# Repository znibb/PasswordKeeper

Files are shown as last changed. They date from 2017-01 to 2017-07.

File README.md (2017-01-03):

# PasswordKeeper
Ever gotten tired manually inputing your password everytime you unlock your desktop? PasswordKeeper let's you use a RFID/NFC tag to input a password into your computer!
## About

The device consists of a custom designed circuit that uses an Atmega32u4 MCU to interface a MFRC522 contactless reader to any computer by emulating a keyboard over a USB connection, no driver or external software required!

The device stores a list of tags with an assoiciated password in the EEPROM of the MCU. When a user scans a tag the program returns the corresponding password as emulated keyboard presses. The sketch used to store user credentials in EEPROM can be found here: https://github.com/znibb/PasswordKeeper_loadData/.

## Usage
### Store user credentials
1. Download the loadData sketch from: https://github.com/znibb/PasswordKeeper_loadData/.
2. Copy `src/PasswordKeeper_loadData.ino.template` to `src/PasswordKeeper_loadData.ino`.
3. Edit loadData sketch with appropriate user credentials.
4. Upload loadData sketch.
5. Open a serial connection to the device to initialize the writing to EEPROM and to get feedback on the results.
6. Done.

### Prepare for operation
1. Clone/download the sketch from this repository.
2. Upload sketch.
3. Ready for use!

## Tips & tricks
- Don't know the UID of your tag? 
  - Upload the sketch and start a serial monitor. The sketch will output the UID of any scanned tag on the serial bus.

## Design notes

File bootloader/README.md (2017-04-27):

# Bootloader tools
* Software
  - Blink.hex
    - Compiled standard Blink sketch.
  - Blink_with_bl.hex
    - Same as above but also contains the bootloader section.
  - Caterina-Leonardo.hex
    - Standard Arduino Leonardo bootloader.
* Scripts
  - dfuUpload.sh
    - Flash software over USB to a MCU in DFU mode.
  - load_bootloader.sh
    - Burn bootloader using avrdude and a AVRISP2 programmer.
  - read_fuses.sh
    - Read out fuse values using avrdude and a AVRISP2 programmer. Stores the values in separate txt files.
  - write_fuses.sh
    - Set fuse values to suitable values, described in 'fuses.txt'
* Information
  - fuses.txt
    - Explains the used fuse values

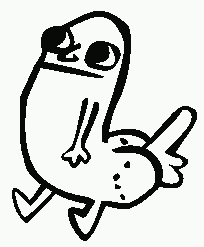
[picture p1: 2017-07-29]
hardware/db_204x247.bmp

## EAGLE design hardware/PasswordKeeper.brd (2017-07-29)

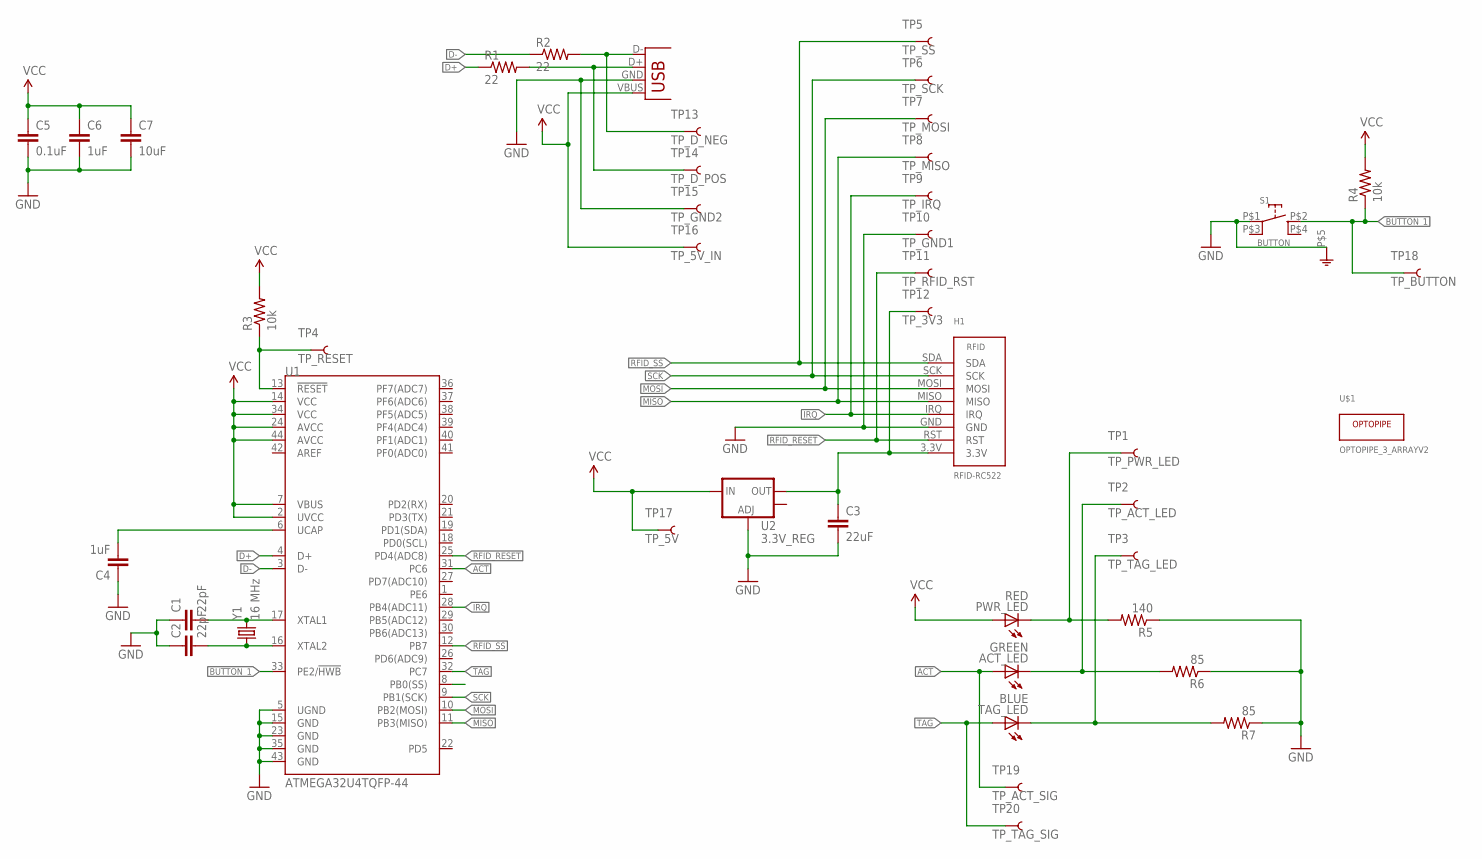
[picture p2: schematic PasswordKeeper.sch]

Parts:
ACT_LED: GREEN; LED-1206
C1, C2: 22pF; 1206
C3: 22uF; 0805
C4, C6: 1uF; 1206
C5: 0.1uF; 1206
C7: 10uF; 1206
H1: RFID-RC522; EXT_RFID_READER
JP1: USB-A-H
PWR_LED: RED; LED-1206
R1, R2: 22; 1206
R3, R4: 10k; 1206
R5: 140; 1206
R6, R7: 85; 1206
S1: BUTTON; TACTILE_SWITCH_SMD_RIGHT_ANGLE
TAG_LED: BLUE; LED-1206
TP1: TP_PWR_LED; TP_15TH
TP2: TP_ACT_LED; TP_15TH
TP3: TP_TAG_LED; TP_15TH
TP4: TP_RESET; TP_15TH
TP5: TP_SS; TP_15TH
TP6: TP_SCK; TP_15TH
TP7: TP_MOSI; TP_15TH
TP8: TP_MISO; TP_15TH
TP9: TP_IRQ; TP_15TH
TP10: TP_GND1; TP_15TH
TP11: TP_RFID_RST; TP_15TH
TP12: TP_3V3; TP_15TH
TP13: TP_D_NEG; TP_15TH
TP14: TP_D_POS; TP_15TH
TP15: TP_GND2; TP_15TH
TP16: TP_5V_IN; TP_15TH
TP17: TP_5V; TP_15TH
TP18: TP_BUTTON; TP_15TH
TP19: TP_ACT_SIG; TP_15TH
TP20: TP_TAG_SIG; TP_15TH
U1: ATMEGA32U4TQFP-44; TQFP44
U2: 3.3V_REG; SOT223
U$1: OPTOPIPE_3_ARRAYV2; 515-1000_V2
Y1: 16 MHz; HC49UP

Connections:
3.3V: C3.1, H1.3.3V, TP12.P$1, U2.2 (OUT)
ACT: ACT_LED.A, TP19.P$1, U1.31 (PC6)
BUTTON_1: R4.1, S1.P$2, TP18.P$1, U1.33 (PE2/!HWB)
D+: R1.1, U1.4 (D+)
D-: R2.1, U1.3 (D-)
GND: C1.1, C2.1, C3.2, C4.1, C5.2, C6.2, C7.2, H1.GND, JP1.GND (VBUS), R5.1, R6.1, R7.1, S1.P$1, S1.P$5, TP10.P$1, TP15.P$1, U1.5 (UGND), U1.15 (GND), U1.23 (GND), U1.35 (GND), U1.43 (GND), U2.1 (ADJ)
IRQ: H1.IRQ, TP9.P$1, U1.28 (PB4(ADC11))
MISO: H1.MISO, TP8.P$1, U1.11 (PB3(MISO))
MOSI: H1.MOSI, TP7.P$1, U1.10 (PB2(MOSI))
unnamed: JP1.D- (D+), R2.2, TP13.P$1
unnamed: JP1.D+ (D-), R1.2, TP14.P$1
unnamed: C1.2, U1.17 (XTAL1), Y1.2
unnamed: C2.2, U1.16 (XTAL2), Y1.1
unnamed: C4.2, U1.6 (UCAP)
unnamed: PWR_LED.C, R5.2, TP1.P$1
unnamed: ACT_LED.C, R6.2, TP2.P$1
unnamed: R7.2, TAG_LED.C, TP3.P$1
PROG_SS: U1.8 (PB0(SS))
RESET: R3.1, TP4.P$1, U1.13 (!RESET)
RFID_RESET: H1.RST, TP11.P$1, U1.25 (PD4(ADC8))
RFID_SS: H1.SDA, TP5.P$1, U1.12 (PB7)
SCK: H1.SCK, TP6.P$1, U1.9 (PB1(SCK))
TAG: TAG_LED.A, TP20.P$1, U1.32 (PC7)
VCC: C5.1, C6.1, C7.1, JP1.VBUS (GND), PWR_LED.A, R3.2, R4.2, TP16.P$1, TP17.P$1, U1.2 (UVCC), U1.7 (VBUS), U1.14 (VCC), U1.24 (AVCC), U1.34 (VCC), U1.44 (AVCC), U2.3 (IN)

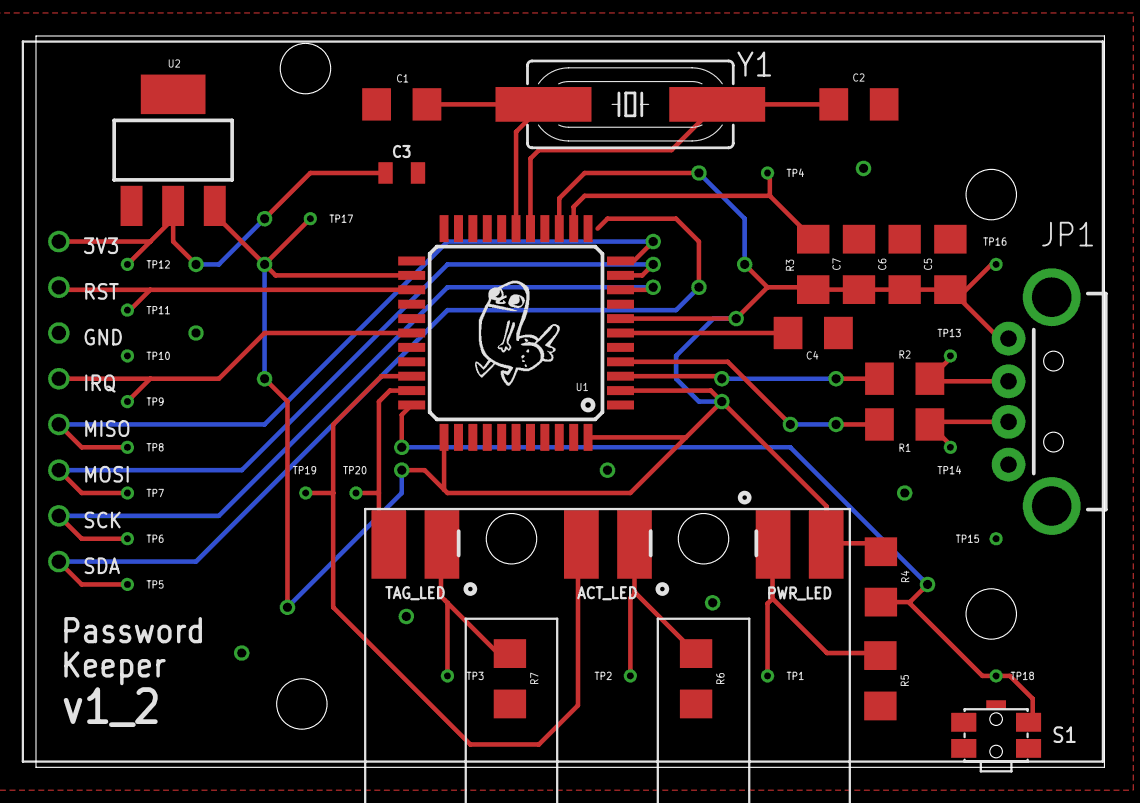
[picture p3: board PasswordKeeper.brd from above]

Board: 2 copper layers, 59.4 x 40.6 mm, 44 parts (0 on the bottom side), 23 nets.

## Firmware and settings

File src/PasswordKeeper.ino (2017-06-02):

#include <Arduino.h>
#include <EEPROM.h>
#include <Keyboard.h>
#include <MFRC522.h>
#include <TagData.h>

//#define DEBUG

// Pin definitions
#define RST_PIN 4
#define SS_PIN 11
#define ACT_LED_PIN 5
#define TAG_LED_PIN 13
#define BUTTON_PIN "PE2"

// Parameters
const int blinkDelay = 500;
const int authDelay = 2000;
const int tagDelay = 1000;
const int loopDelay = 1000;

// Variables
unsigned long actExpirationTime;
unsigned long tagExpirationTime;
byte nbr_of_tags;
byte uid_size;
byte pwd_size;

// Object for containing user data
TagData userData;

// Initialize RFID reader object
MFRC522 rfid(SS_PIN, RST_PIN);

// Function prototypes
boolean buttonState(String);
boolean checkPair(byte[], byte[]);
void enableLed(byte, const int);
void flashLeds(byte);
void ledHandler(void);

void setup(){
  // Init serial port
  Serial.begin(115200);

  #ifdef DEBUG
  // Wait for  serial port to start so no printouts are missed
  while(!Serial);
  #endif

  // Init RFID reader
  SPI.begin();
  rfid.PCD_Init();

  // Adjust RFID reader antenna gain
  rfid.PCD_SetAntennaGain(rfid.RxGain_max);

  // Set pin modes
  pinMode(ACT_LED_PIN, OUTPUT);
  pinMode(TAG_LED_PIN, OUTPUT);
  DDRE &= B11111011;  // Set PE2 as input

  // Load user meta data from EEPROM
  nbr_of_tags = EEPROM.read(0);
  uid_size    = EEPROM.read(1);
  pwd_size    = EEPROM.read(2);

  // Initialize data storage object
  userData = TagData(nbr_of_tags, uid_size, pwd_size);

  // Load user data from EEPROM
  int memAddr = 3;  // User data starts at the 4th byte (index 3)
  // Parse one uid/pwd pair at a time
  for(int i = 0; i < nbr_of_tags; i++){
    // Parse uid
    byte uid[uid_size];
    for(int j = 0; j < uid_size; j++){
      uid[j] = EEPROM.read(memAddr);
      memAddr++;
    }
    userData.tags[i].setUid(uid);

    // Parse password
    char pwd[pwd_size];
    for(int j = 0; j < pwd_size; j++){
      pwd[j] = EEPROM.read(memAddr);
      memAddr++;
    }
    userData.tags[i].setPwd(pwd);
  }
  Serial.print("Loaded ");
  Serial.print(nbr_of_tags);
  Serial.println(" tags.");

//=============================================
  #ifdef DEBUG
  // Dump all retrieved data to Serial
  byte uid[uid_size];
  char pwd[pwd_size];

  for(int i = 0; i < nbr_of_tags; i++){
    userData.tags[i].getUid(uid);
    for(int j = 0; j < uid_size; j++){
      Serial.print(uid[j] < 0x10 ? " 0" : " ");
      Serial.print(uid[j], HEX);
    }
    Serial.print(" - ");

    userData.tags[i].getPwd(pwd);
    Serial.print(pwd);
  }
  #endif
//=============================================

  // Flash leds to indicate end of setup
  flashLeds(2);
}

void loop(){
  // Run subroutine to check of any LEDs should be turned off
  ledHandler();

  // Check for button press
  if(buttonState(BUTTON_PIN)){
    enableLed(TAG_LED_PIN, tagDelay);
  }

  // Check if a new tag is detected and return if none are found
  if(!rfid.PICC_IsNewCardPresent() || !rfid.PICC_ReadCardSerial()){
    return;
  }

  // Blink TAG LED once to show that a tag has been read
  enableLed(TAG_LED_PIN, tagDelay);

  // Read tag uid
  byte readUID[rfid.uid.size];
  Serial.print("Read Card UID:");
  for(byte i = 0; i < rfid.uid.size; i++){
    readUID[i] = rfid.uid.uidByte[i];
    Serial.print(readUID[i] < 0x10 ? " 0" : " ");
    Serial.print(readUID[i], HEX);
  }
  Serial.println();

  // Check if read uid matches any of the known tags
  bool match = false;
  char index = userData.getIndexOf(readUID, rfid.uid.size);
  if(index >= 0){
    match = true;
  }

  // If tag is known output the corresponding password and blink ACT LED
  if(match){
    Serial.println("Authorized");
    char pwd[pwd_size];
    userData.tags[index].getPwd(pwd);
    Keyboard.print(pwd);
    enableLed(ACT_LED_PIN, authDelay);
  }
  else{
    Serial.println("Unauthorized");
  }

  // Delay loop execution to prevent tag from being read multiple times in succession
  delay(loopDelay);
}

// Return button state using direct port manipulation
boolean buttonState(String button){
  // Desired input port specified as String
  if(button.compareTo(BUTTON_PIN) == 0){
    if((PINE & B00000100) == 0){
      Serial.println("Button pressed");
      return true;
    }
    else{
      return false;
    }
  }
  else{
    return false;
  }
}

// Enables a LED and stores the planned time for turn off (to be used by ledHandler)
void enableLed(byte led, const int duration){
  if(led == ACT_LED_PIN){
    actExpirationTime = millis() + duration;
    digitalWrite(ACT_LED_PIN, HIGH);
  }
  else if(led == TAG_LED_PIN){
    tagExpirationTime = millis() + duration;
    digitalWrite(TAG_LED_PIN, HIGH);
  }
}

// Alternate flashing LEDs with a specified amount of cycles
void flashLeds(byte count){
  for(byte i = 0; i < count; i++){
    digitalWrite(ACT_LED_PIN, HIGH);
    digitalWrite(TAG_LED_PIN, LOW);
    delay(blinkDelay);
    digitalWrite(ACT_LED_PIN, LOW);
    digitalWrite(TAG_LED_PIN, HIGH);
    delay(blinkDelay);
  }
  digitalWrite(ACT_LED_PIN, LOW);
  digitalWrite(TAG_LED_PIN, LOW);
}

// Check if any of the LEDs have passed their duration and should be turned off
void ledHandler(){
  unsigned long currentTime = millis();
  if(digitalRead(ACT_LED_PIN) == HIGH && currentTime >= actExpirationTime){
    digitalWrite(ACT_LED_PIN, LOW);
  }
  if(digitalRead(TAG_LED_PIN) == HIGH && currentTime >= tagExpirationTime){
    digitalWrite(TAG_LED_PIN, LOW);
  }
}

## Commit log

2016-11-26 Added fuse printout files to .gitignore
2016-12-01 Updated fuse values
2016-12-10 Increased antenna gain and fixed error in reading button state
    [PasswordKeeper.ino]
2017-05-31 Added PCB files
    [PasswordKeeper_v1_2.brd, PasswordKeeper_v1_2.sch]
2017-06-02 Revert "Added PCB files"
    This reverts commit 08d9288e047e3d3013372883bf24a64ee6211b8b.
    [PasswordKeeper_v1_2.brd, PasswordKeeper_v1_2.sch]
2017-06-02 Revert "Initial commit". Messed up commit messages.
    This reverts commit a167ed2f3c9f163b5252ba3184aee50a860bac41.
    [PasswordKeeper.ino]
2017-07-29 Added gerber zip for version 1.2
2017-07-29 HW version 1.2
    [PasswordKeeper.brd, PasswordKeeper.sch]

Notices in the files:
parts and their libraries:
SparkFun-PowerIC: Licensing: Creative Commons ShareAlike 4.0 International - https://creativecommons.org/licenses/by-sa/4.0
